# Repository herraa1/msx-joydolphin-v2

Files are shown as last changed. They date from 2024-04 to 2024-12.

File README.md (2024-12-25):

# Nintendo Gamecube controller adapter for MSX (msx-joydolphin) v2

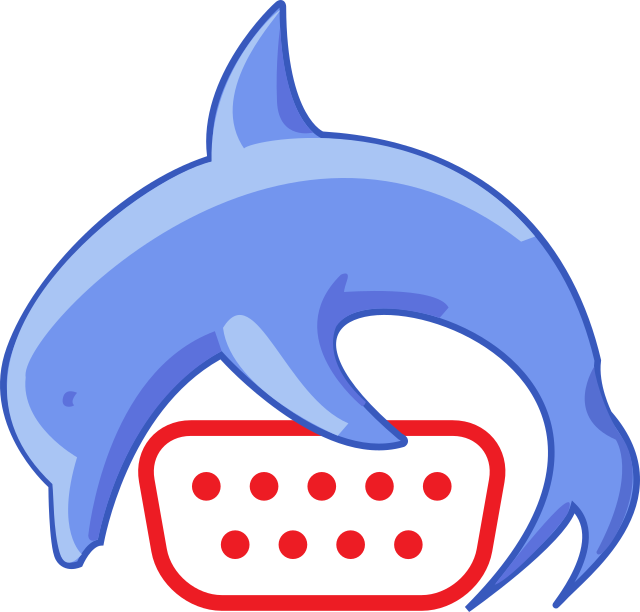
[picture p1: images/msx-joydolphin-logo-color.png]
[](images/msx-joydolphin-logo-color.png)

Connect [Nintendo Gamecube controllers](https://en.wikipedia.org/wiki/GameCube_controller) to [MSX computers](https://www.msx.org/wiki/).

> [!NOTE]
>
> No build instructions are yet provided, but if you are brave enough go for the [recommended build](#recommended-build).
>

## Introduction

The msx-joydolphin v2 is an adapter that allows connecting Nintendo Gamecube controllers to [MSX general purpose I/O ports](https://www.msx.org/wiki/General_Purpose_port).

The main features of the msx-joydolphin v2 adapter are:
* small footprint
* made of widely available electronic components
* behaves as a cord extension between the MSX computer and the Nintendo Gamecube controller
* uses a female standard DE9 connector on the adapter's MSX joystick side
* uses a Gamecube Controller socket on the adapter's Nintendo Gamecube controller side
* no need for external power supply for wired controllers, the adapter draws current from the MSX port
* low power consumption for wired controllers (<20mA)
* serial debug provides information about the operation of the adapter
* supports WaveBird Wireless Controllers (which draw up to 150mA) when powering the adapter via USB

## Changes since v1

The msx-joydolphin v2 adapter now follows the behavior of the MSX joystick reference diagram of the MSX Technical Databook,
even when pin8 of the MSX general purpose I/O port is HIGH.
This makes the adapter now work seamlessly with MSX-HID, which required entering FM Towns compatibility mode
in msx-joydolphin v1.

## Adapter Name

Why msx-joydolphin?
The first part of the name is pretty obvious: _"msx"_ as this is an adapter for MSX computers and _"joy"_ as this is a joystick adapter.
The _"dolphin"_ part comes from the project codename assigned to the Nintendo Gamecube during its development.

## [Hardware](hardware/kicad/)

The msx-joydolphin v2 adapter uses an [Arduino Nano](https://store.arduino.cc/products/arduino-nano) to convert the [Nintendo Gamecube controller signalling](http://www.int03.co.uk/crema/hardware/gamecube/gc-control.html) to the [MSX joystick standard signalling](https://www.msx.org/wiki/Joystick_control).

A small printed circuit board (PCB) is used to easily bind all components:
* The Arduino Nano is connected using female headers (or soldered directly, when using the proposed the plastic case)
* PH2.0 connectors are used to connect cable extensions
* A 2.54 pitch debug header is added for convenience
* Through-hole components are used on the front side
* Surface mount device (SMD) components are used on the back side
  * The SMD components use footprints and sizes (1206) to make hand-soldering easier

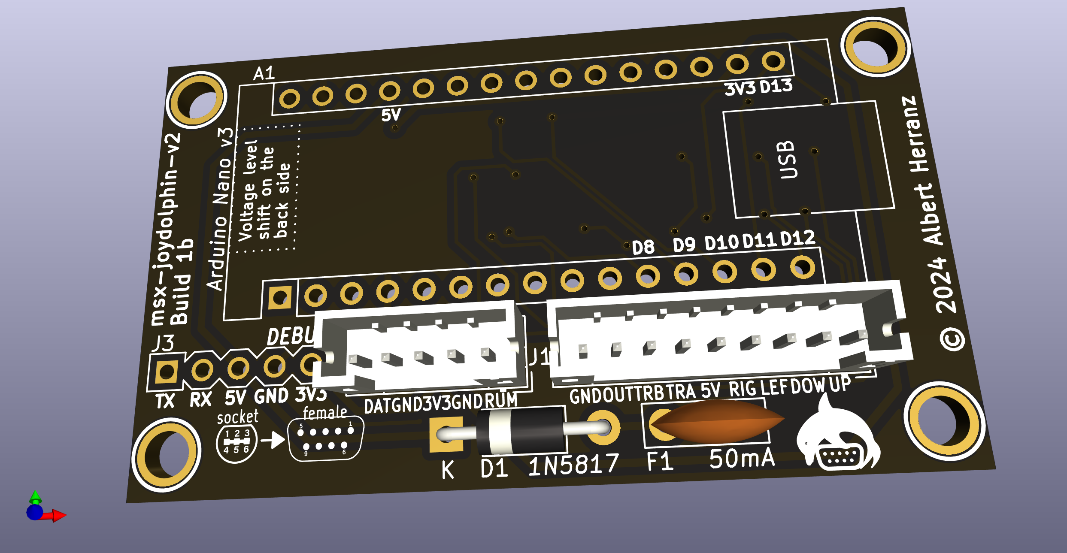
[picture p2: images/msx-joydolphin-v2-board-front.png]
[](images/msx-joydolphin-v2-board-front.png)
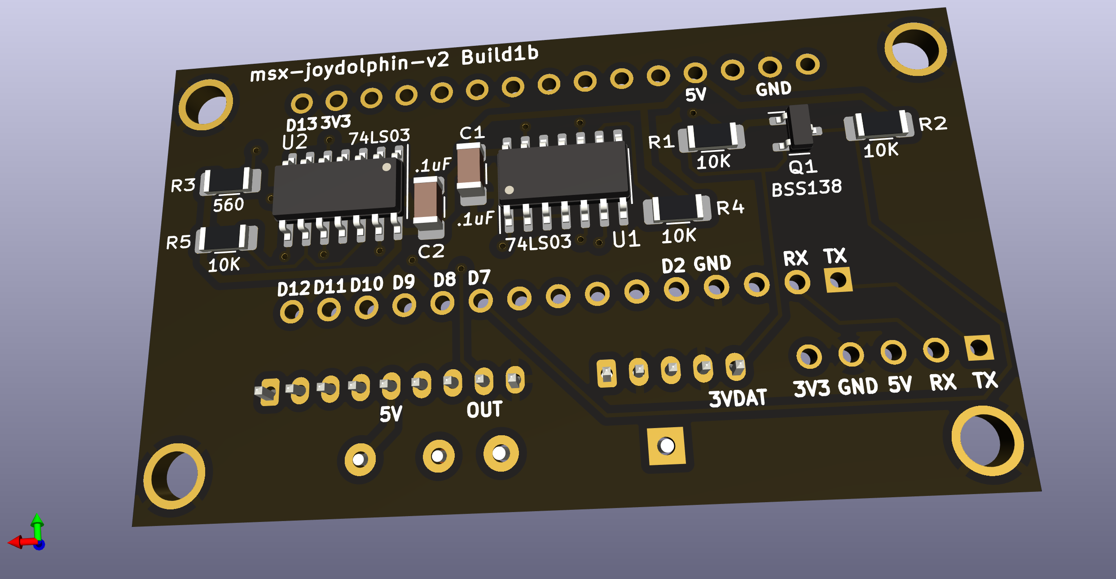
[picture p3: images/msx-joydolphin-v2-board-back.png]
[](images/msx-joydolphin-v2-board-back.png)

Connection to the MSX general purpose I/O port is implemented using a DE9 joystick extension cable with a female DE9 connector on one side and a loose end on the other side.
The MSX joystick extension cable loose end is wired according to the following pinout mapping.

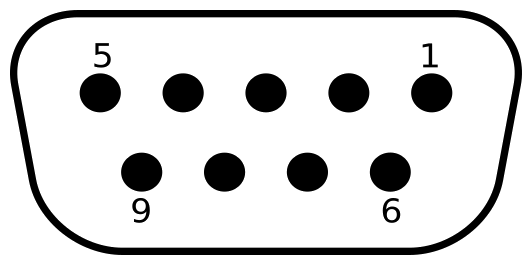
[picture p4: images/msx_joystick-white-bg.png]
| [](images/msx_joystick-white-bg.png) |
|:--|
| MSX joystick connector pinout, from controller plug side |

| MSX side pin | Cable color (may vary) | Signal | Arduino Nano side (port/pin/number) |
| --- | --- | --- | --- |
| 5 | Brown | +5v | _/5V/27 |
| 4 | Orange | RIGHT  | PB3/D11/14 |
| 3 | Grey | LEFT | PB2/D10/13 |
| 2 | Black | DOWN | PB1/D9/12 |
| 1 | Red | UP | PB0/D8/11 |
| 6 | Green | TRIGA  | PB4/D12/15 |
| 7 | White | TRIGB  | PB5/D13/16 |
| 8 | Blue | OUT | PD2/D2/5 |
| 9 | Yellow | GND | _/GND/4,29 |

The msx-joydolphin-v2 is fully compatible with MSX joysticks and honors the pin8 (OUT) signal.

The adapter uses open collector outputs (using 74LS03 Quad 2-Input NAND gates with open collector outputs) which makes the adapter safer [^3] than the
standard MSX joystick schematic depicted in the MSX Technical Data Book, as it avoids a series of undesired conditions that can lead to bus contention/short circuits.

Power is drawn from the +5V signal of the MSX general purpose I/O port, which is capable of delivering up to 50mA [^1].
The msx-joydolphin v2 draws below 20mA from the port when a wired controller is connected, so it is on the safe side. Anyway, the msx-joydolphin adapter uses a Positive Temperature Coeficient (PTC) resettable fuse of 50mA (F1) to limit current in case something goes wrong.

Also on the power side, a [1N5817 Schottky diode](https://www.onsemi.com/download/data-sheet/pdf/1n5817-d.pdf) (D1) is used to avoid leaking current from the msx-joydolphin adapter to the MSX in case the USB port of the Arduino Nano is connected to a computer or power supply while the adapter is plugged into an MSX.

Connection to the Nintendo Gamecube controller is done via a Nintendo Gamecube controller extension cable with a controller socket on one side and a loose end on the other side.
The Nintendo Gamecube controller extension cable loose end is wired according to the following pinout mapping.

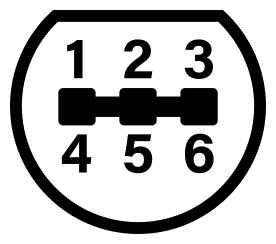
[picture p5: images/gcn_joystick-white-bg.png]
| [](images/gcn_joystick-white-bg.png) |
|:--|
| Nintendo Gamecube connector pinout, from Nintendo Gamecube side |

| Gamecube socket pin | Cable color official | Cable color actual (may vary) | Signal | Comment | Arduino Nano side (port/pin/number) |
| --- | ---| --- | --- | --- | --- |
| 1 | Yellow | White | +5v | rumble, not used | N/C |
| 2 | Red | Red | DAT | data line, uses 3v3 logic so it connects via a level shifter to PD7/D7/10 | \*( PD7/D7/10 ) |
| 3 | Green | Black | GND | ground | _/GND/4,29 |
| 4 | White | Blue | GND | ground | _/GND/4,29 |
| 5 | | | | | N/C |
| 6 | Blue | Green | 3.43v  | power line, 3v3 | _/3v3/17 |
| 7 | Black | N/A | GND | ground | N/C |

The Nintendo Gamecube controller uses 3.3V for power and logic, except for the rumble motor which uses 5V.

Power for the Nintendo Gamecube controller is provided by the 3.3V pin of the FT232RL integrated in the Arduino Nano, which is capable of delivering up to 50mA [^2], enough to power a wired game controller.

As the Arduino Nano is a 5V logic microcontroller, the msx-joydolphin adapter uses a voltage level shifter based on the [BSS138 N-Channel Logic Level Enhancement Mode Field Effect Transistor](https://www.onsemi.com/pdf/datasheet/bss138-d.pdf) (Q1) to convert the Nintendo Gamecube controller DAT signal between 3.3V and 5V logic levels.

> [!WARNING]
> Do NOT connect the DAT line of the Nintendo Gamecube controller to the Arduino Nano directly, always use a voltage level shifter.
> The game controller may get damaged if you connect a 5V signal directly to the 3.3V DAT line.

If a WaveBird Wireless Controller is connected then the msx-joydolphin adapter needs to be powered via the mini USB port of the Arduino Nano, as the power consumption (150mA) is higher than what the MSX joystick port can deliver.
Althought it won't work, it is safe to connect a WaveBird Wireless Controller dongle without connecting an external USB power supply thanks to the current limitation of the PTC.
Also, connection of an external USB power supply to the Arduino Nano won't back-power the MSX computer thanks to the Schottky diode reverse current protection.

### Recommended Build

Please, use [msx-joydolphin-v2 Build1b](#build1b) for making new boards if you want something field-tested.

### [Build1b](hardware/kicad/msx-joydolphin-v2-Build1b)

[Bill Of Materials (BoM)](https://html-preview.github.io/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)

The Build1b adapter mimics completely the standard MSX joystick behaviour:

* When pin8 is HIGH, the adapter puts all stick and triggers signals in high impedance mode irrespective of their status (as if stick and triggers were not hold in the standard MSX joystick schematic), which become HIGH on the MSX side via the MSX PSG related circuitry pull-ups (matching the expected behavior)
* When pin8 is LOW
  * if a stick direction or trigger is hold, the corresponding signal is pulled down to GND causing it to be LOW (matching the expected behavior)
  * if a stick direction or trigger is not hold, the corresponding signal is put in high impedance mode, which becomes HIGH on the MSX side via the MSX PSG related circuitry pull-ups (matching the expected behaviour)

This build uses discrete logic components to honor the pin8 signaling (two [74LS03DR quad 2-input positive-nand gates with open collector outputs](https://www.ti.com/lit/ds/symlink/sn74ls03.pdf)) and uses open collector outputs which makes the adapter safer [^3] than the standard MSX joystick schematic depicted in the MSX Technical Data Book, as it avoids a series of undesired conditions that can lead to bus contention/short circuits.

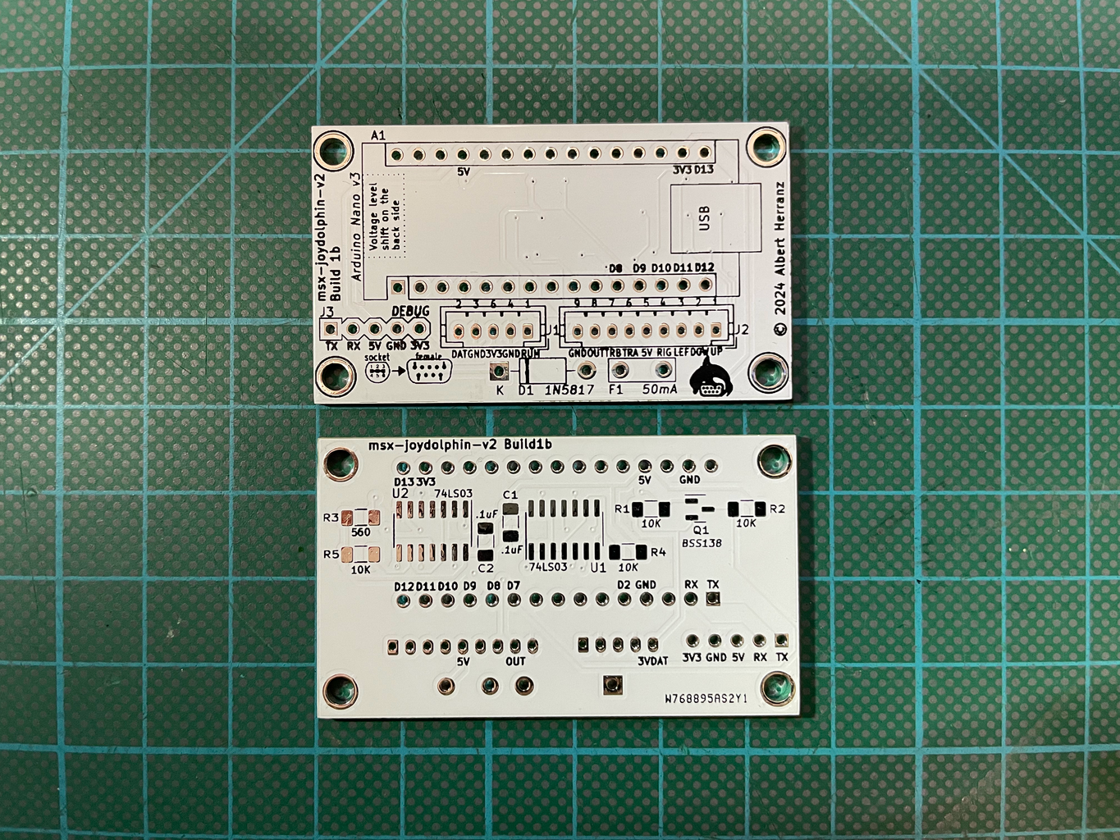
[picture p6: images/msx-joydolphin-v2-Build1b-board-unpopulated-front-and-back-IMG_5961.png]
|[](images/msx-joydolphin-v2-Build1b-board-unpopulated-front-and-back-IMG_5961.png)|
|:--|
|msx-joydolphin-v2 Build1b first prototype unpopulated|

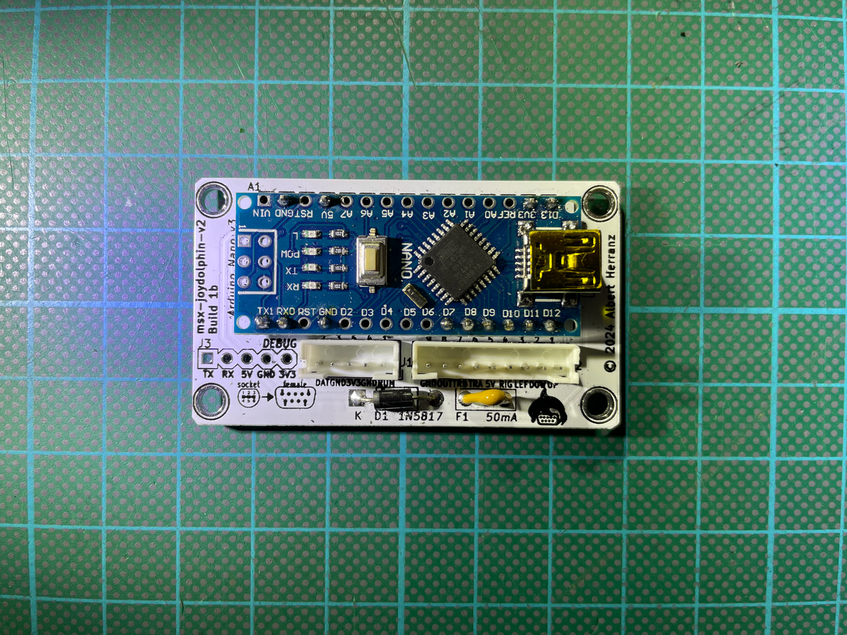
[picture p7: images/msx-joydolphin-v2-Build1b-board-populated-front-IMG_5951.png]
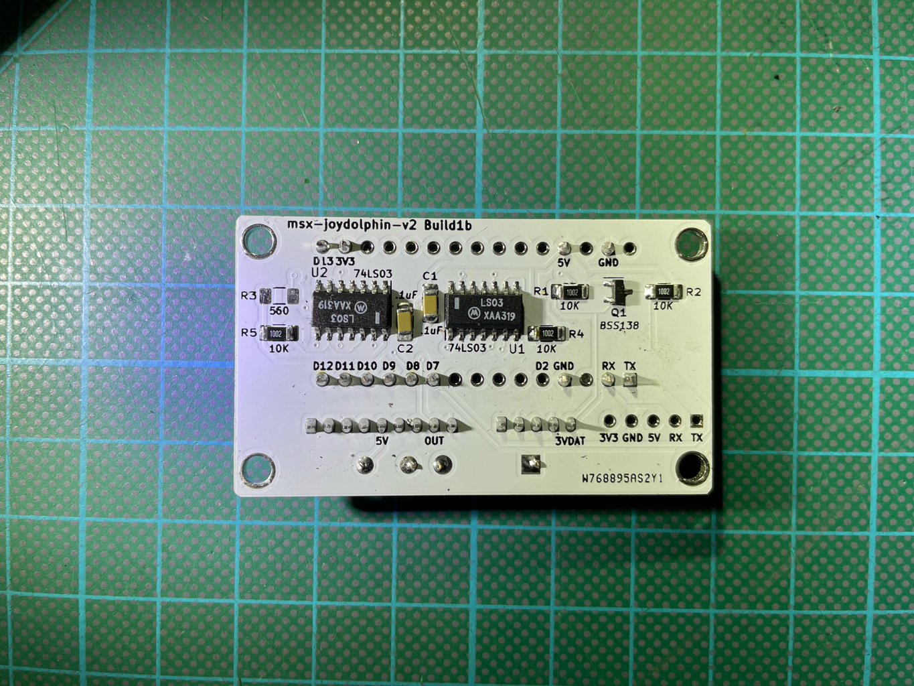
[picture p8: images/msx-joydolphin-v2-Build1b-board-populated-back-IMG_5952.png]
|[](images/msx-joydolphin-v2-Build1b-board-populated-front-IMG_5951.png)|[](images/msx-joydolphin-v2-Build1b-board-populated-back-IMG_5952.png)|
|-|-|
|msx-joydolphin-v2 Build1b front populated|msx-joydolphin-v2 Build1b rear populated|

> [!NOTE]
> Do NOT populate resistor R3 as it is not needed.

## [Firmware](firmware/msx-joydolphin-v2/)

The msx-joydolphin v2 adapter firmware uses [NicoHood's Nintendo library](https://github.com/NicoHood/Nintendo) to read the Nintendo Gamecube controller status, and it is heavily inspired on [Daniel Jose Viana "Danjovic" firmware](https://github.com/Danjovic/MSX/blob/master/NSX-64) for a similar adapter for Nintendo 64 joysticks.

The following elements are used as inputs:
* digital pad (D-Pad), as direction arrows
* analog pad, as direction arrows
* A button, as Trigger 1
* B button, as Trigger 2

Those elements' status are processed by the msx-joydolphin firmware and transformed into MSX general purpose I/O port's signals on the fly.

## [Enclosure](enclosure/)

### Acrylic

A simple acrylic enclosure design for the project is provided to protect the electronic components and provide strain relief for the extension cords.

The enclosure uses a 3mm acrylic sheet.

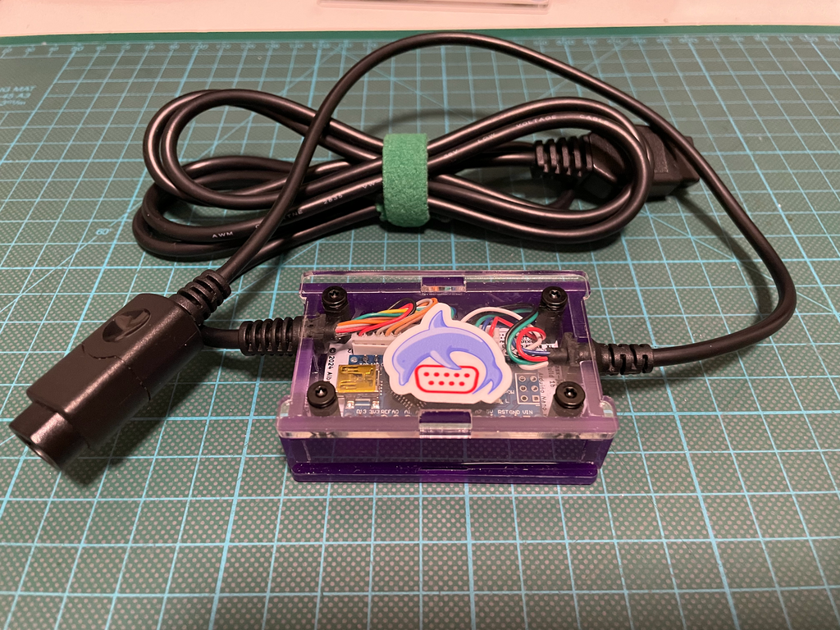
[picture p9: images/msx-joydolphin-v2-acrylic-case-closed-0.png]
[](images/msx-joydolphin-v2-acrylic-case-closed-0.png)
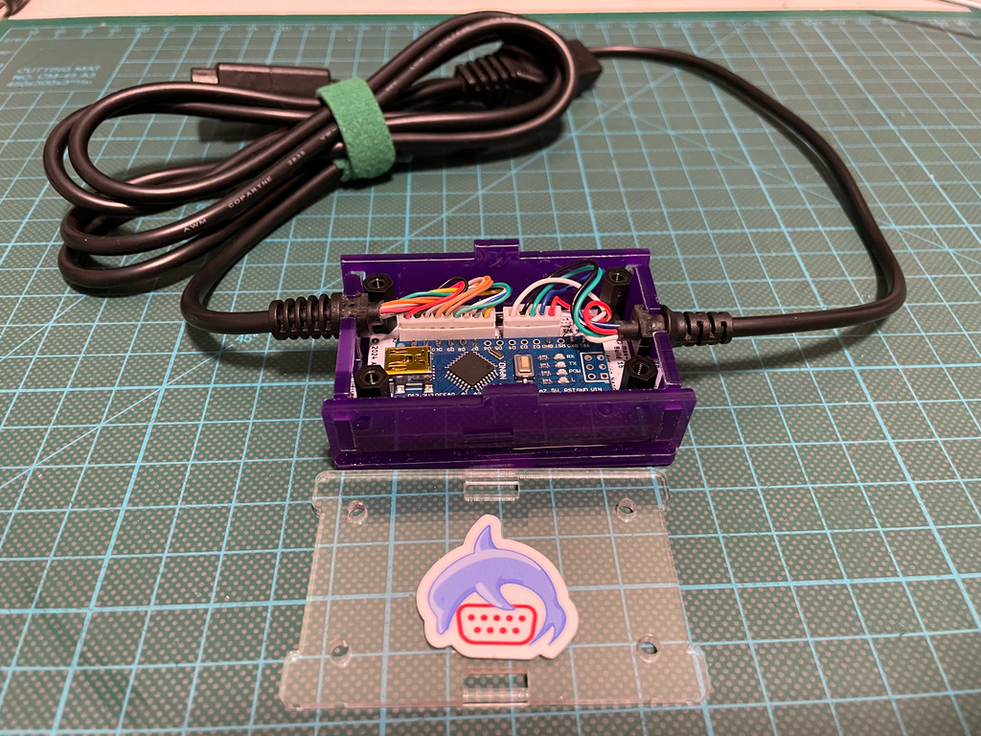
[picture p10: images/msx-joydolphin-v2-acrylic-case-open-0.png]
[](images/msx-joydolphin-v2-acrylic-case-open-0.png)
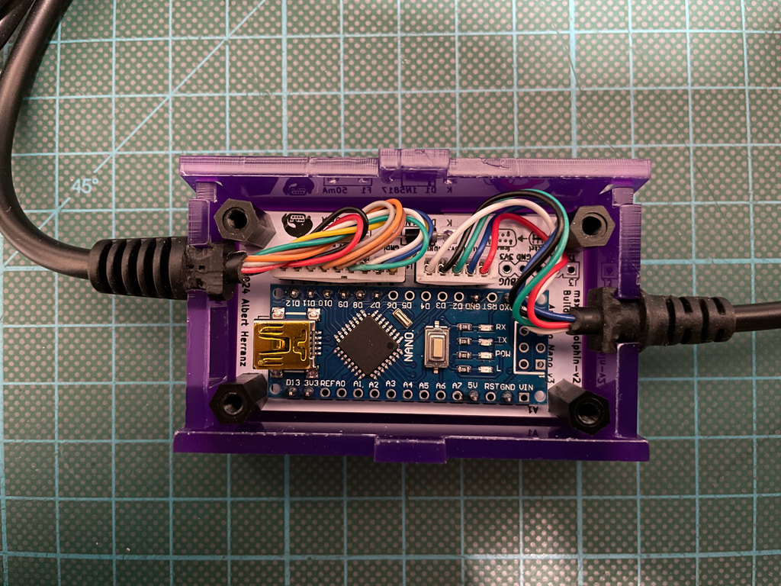
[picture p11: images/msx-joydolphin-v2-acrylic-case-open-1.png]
[](images/msx-joydolphin-v2-acrylic-case-open-1.png)

The enclosure allows access to the USB port of the Arduino Nano without having to open it.

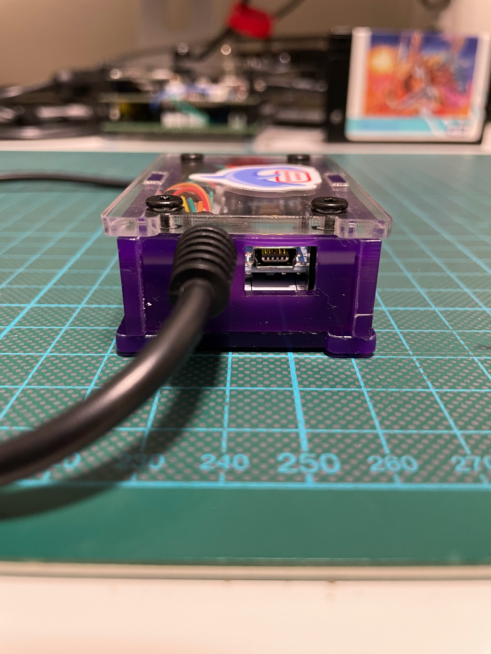
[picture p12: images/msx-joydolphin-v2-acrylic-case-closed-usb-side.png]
[](images/msx-joydolphin-v2-acrylic-case-closed-usb-side.png)

> [!NOTE]
> The height of the acrylic enclosure for msx-joydolphin-v2 has been reduced, so the Arduino Nano must be soldered in the same way as when using the plastic enclosure.

### Plastic

Another enclosure option is using an off-the-shelf [plastic case of 60x36x17mm](https://es.aliexpress.com/item/1005002139025547.html).

When using this option, the Arduino Nano must be soldered directly to the msx-joydolphin v2 board and its pin header legs must be trimmed down in order to fit within the reduced space of the case.

Also, you may need to trim a bit the pcb board corners with a file to slide the board into the case.

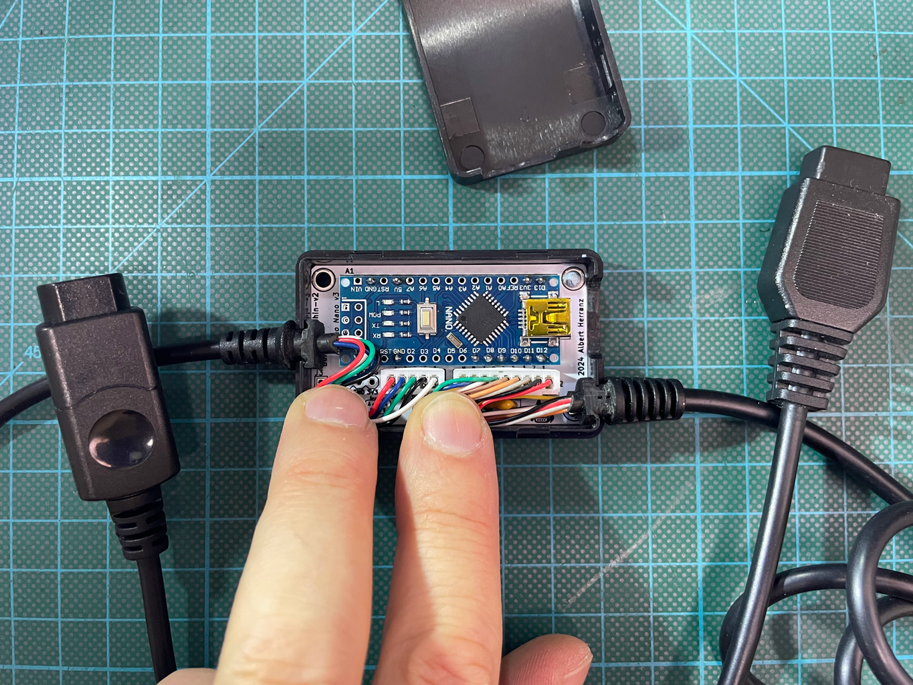
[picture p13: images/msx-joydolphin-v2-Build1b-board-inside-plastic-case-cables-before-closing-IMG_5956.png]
[](images/msx-joydolphin-v2-Build1b-board-inside-plastic-case-cables-before-closing-IMG_5956.png)
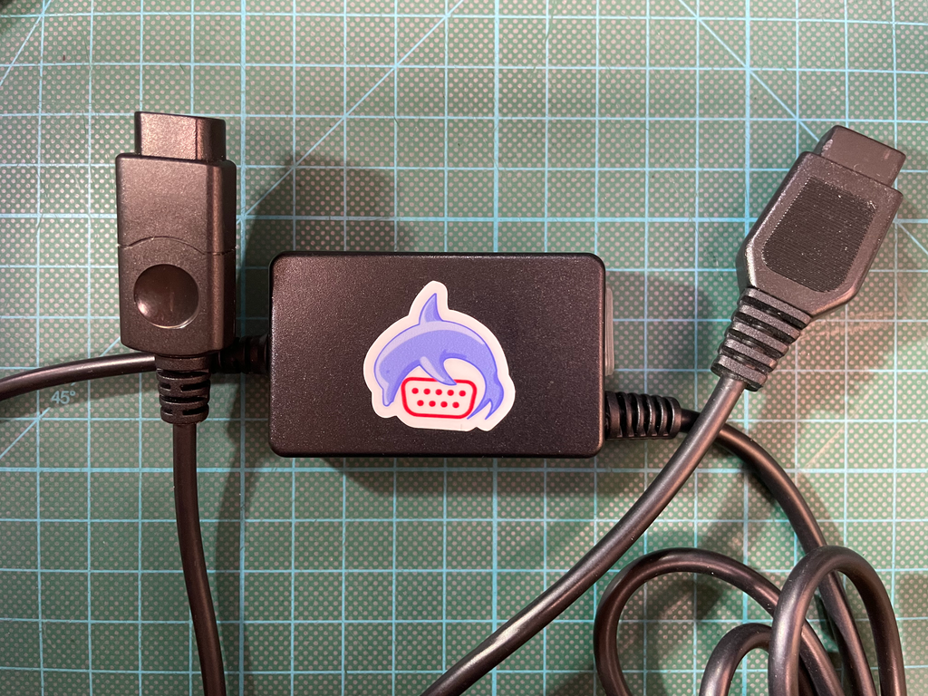
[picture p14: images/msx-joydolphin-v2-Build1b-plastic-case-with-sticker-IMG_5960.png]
[](images/msx-joydolphin-v2-Build1b-plastic-case-with-sticker-IMG_5960.png)

You can enlarge the existing hole on one of the case sides to access the mini USB connector, and make a new hole on the very left of the same side for the MSX joystick cable.

This way you can easily power the adapter via USB when you connect a Wavebird wireless controller.

You can use a plastic cover (a HDMI cover in this case) to protect the mini USB hole when not in use, as seen on the pictures.

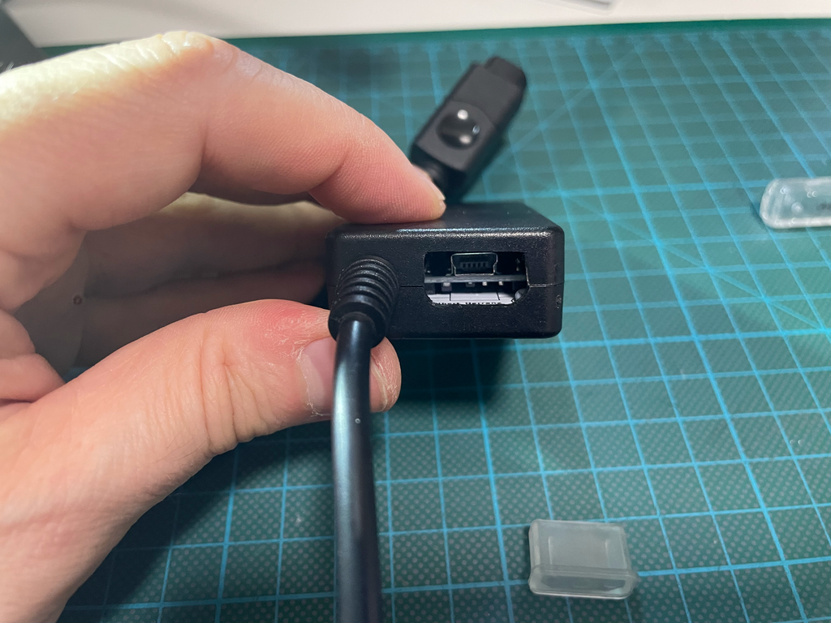
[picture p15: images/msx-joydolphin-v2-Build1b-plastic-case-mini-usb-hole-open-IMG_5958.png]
[](images/msx-joydolphin-v2-Build1b-plastic-case-mini-usb-hole-open-IMG_5958.png)
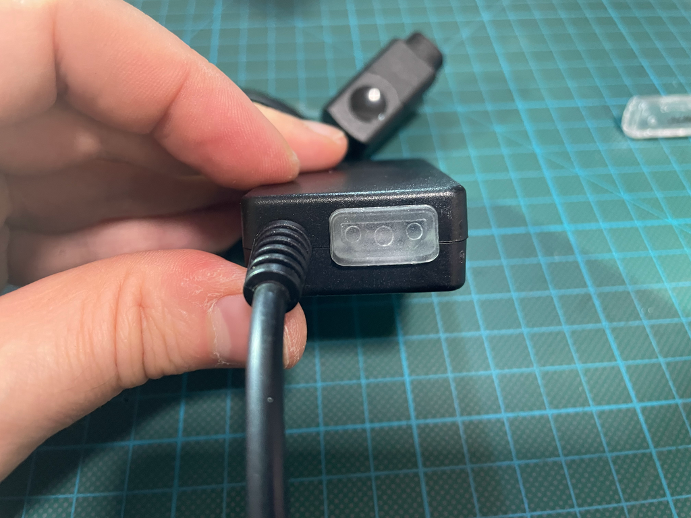
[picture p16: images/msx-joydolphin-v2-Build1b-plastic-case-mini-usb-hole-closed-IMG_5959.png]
[](images/msx-joydolphin-v2-Build1b-plastic-case-mini-usb-hole-closed-IMG_5959.png)

## References

MSX general purpose I/O port
* https://www.msx.org/wiki/General_Purpose_port

Gamecube controller pinout
* https://allpinouts.org/pinouts/connectors/videogame/nintendo-gamecube-controller-connector-pinout/
* http://www.int03.co.uk/crema/hardware/gamecube/gc-control.html

Arduino Nano pinout
* https://content.arduino.cc/assets/Pinout-NANO_latest.pdf
* https://www.makerguides.com/arduino-nano/

Nico Hood Nintendo Gamecube Joystick arduino library
* https://github.com/NicoHood/Nintendo

Daniel Jose Viana "Danjovic" NSX-64 project
* https://github.com/Danjovic/MSX/blob/master/NSX-64

Gamecube controller IDs
* https://www.gc-forever.com/yagcd/chap9.html#sec9

[^1]: https://www.msx.org/wiki/General_Purpose_port
[^2]: https://www.mouser.es/datasheet/2/163/DS_FT232R-11534.pdf
[^3]: https://www.msx.org/wiki/Joystick/joypad_controller (see "Undesired Conditions")

## Image Sources

* https://www.oshwa.org/open-source-hardware-logo/
* https://consolemods.org/wiki/images/a/a1/GameCube_Controller_Pinout.svg
* https://en.wikipedia.org/wiki/File:Numbered_DE9_Diagram.svg
* https://commons.wikimedia.org/wiki/File:Video_Game_Controller_(56427)_-_The_Noun_Project.svg
* https://logo-timeline.fandom.com/wiki/GameCube?file=Nintendo_Dolphin_1999.svg

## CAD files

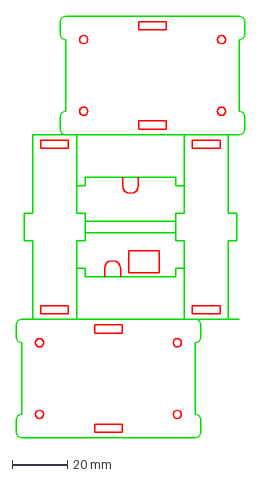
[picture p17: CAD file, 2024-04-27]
enclosure/msx-joydolphin-v2-case-acrylic-3mm-ready-to-lasercut.dxf
83.0 x 153.0 mm

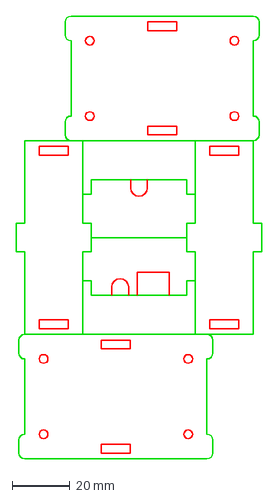
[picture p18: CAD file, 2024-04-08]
enclosure/msx-joydolphin-v2-case.dxf
85.0 x 153.0 mm

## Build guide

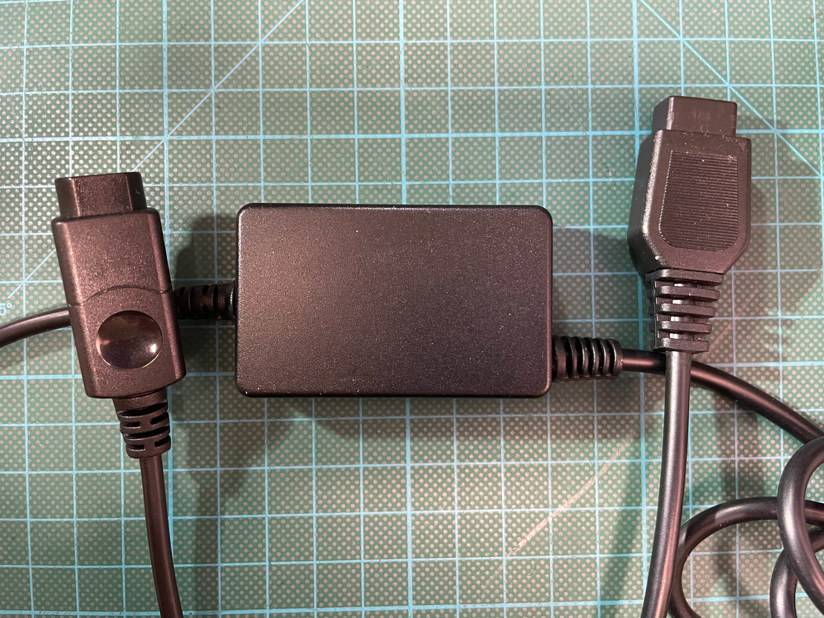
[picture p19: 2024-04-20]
images/msx-joydolphin-v2-Build1b-plastic-case-closed-IMG_5957.png

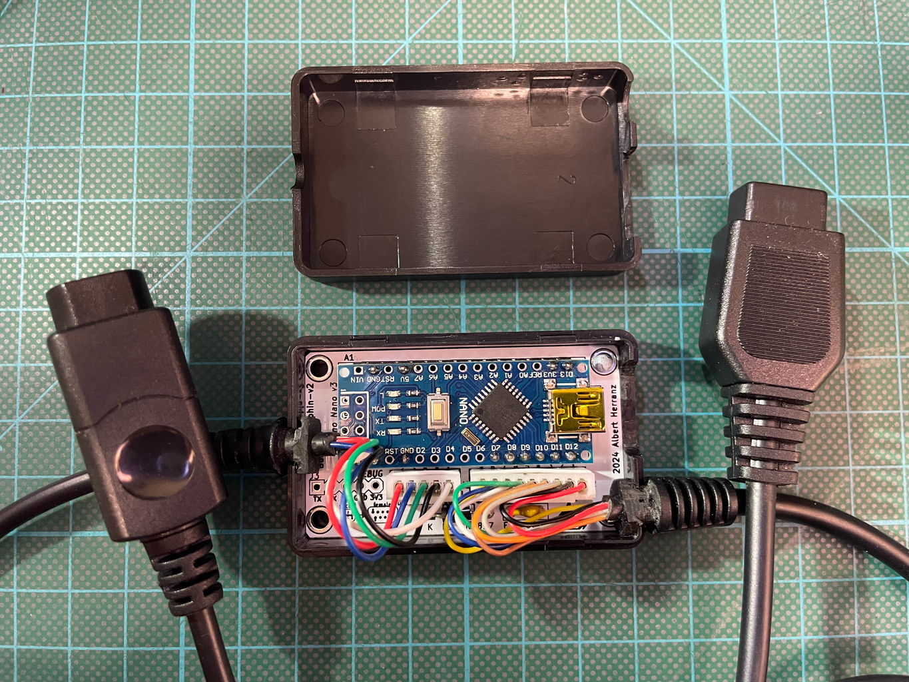
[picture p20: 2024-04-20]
images/msx-joydolphin-v2-Build1b-board-inside-plastic-case-with-gamamecube-and-msx-cable-IMG_5955.png

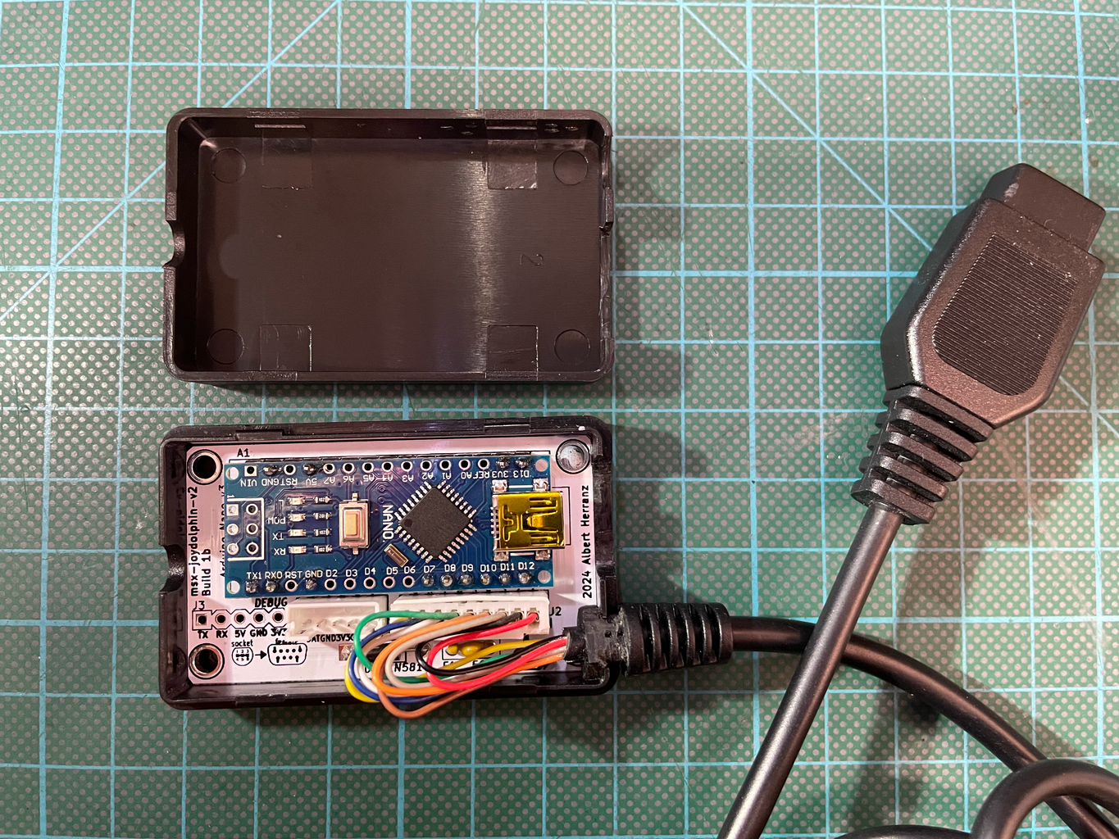
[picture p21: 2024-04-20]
images/msx-joydolphin-v2-Build1b-board-inside-plastic-case-with-msx-cable-IMG_5954.png

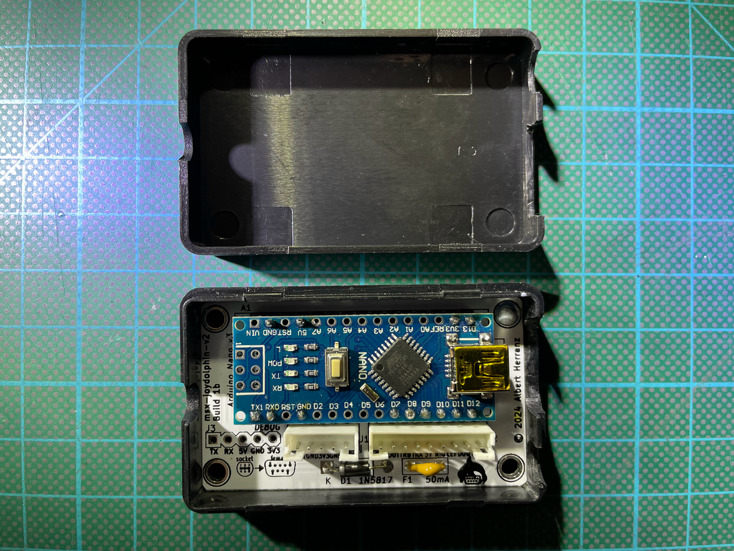
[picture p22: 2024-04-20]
images/msx-joydolphin-v2-Build1b-board-inside-plastic-case-IMG_5953.png

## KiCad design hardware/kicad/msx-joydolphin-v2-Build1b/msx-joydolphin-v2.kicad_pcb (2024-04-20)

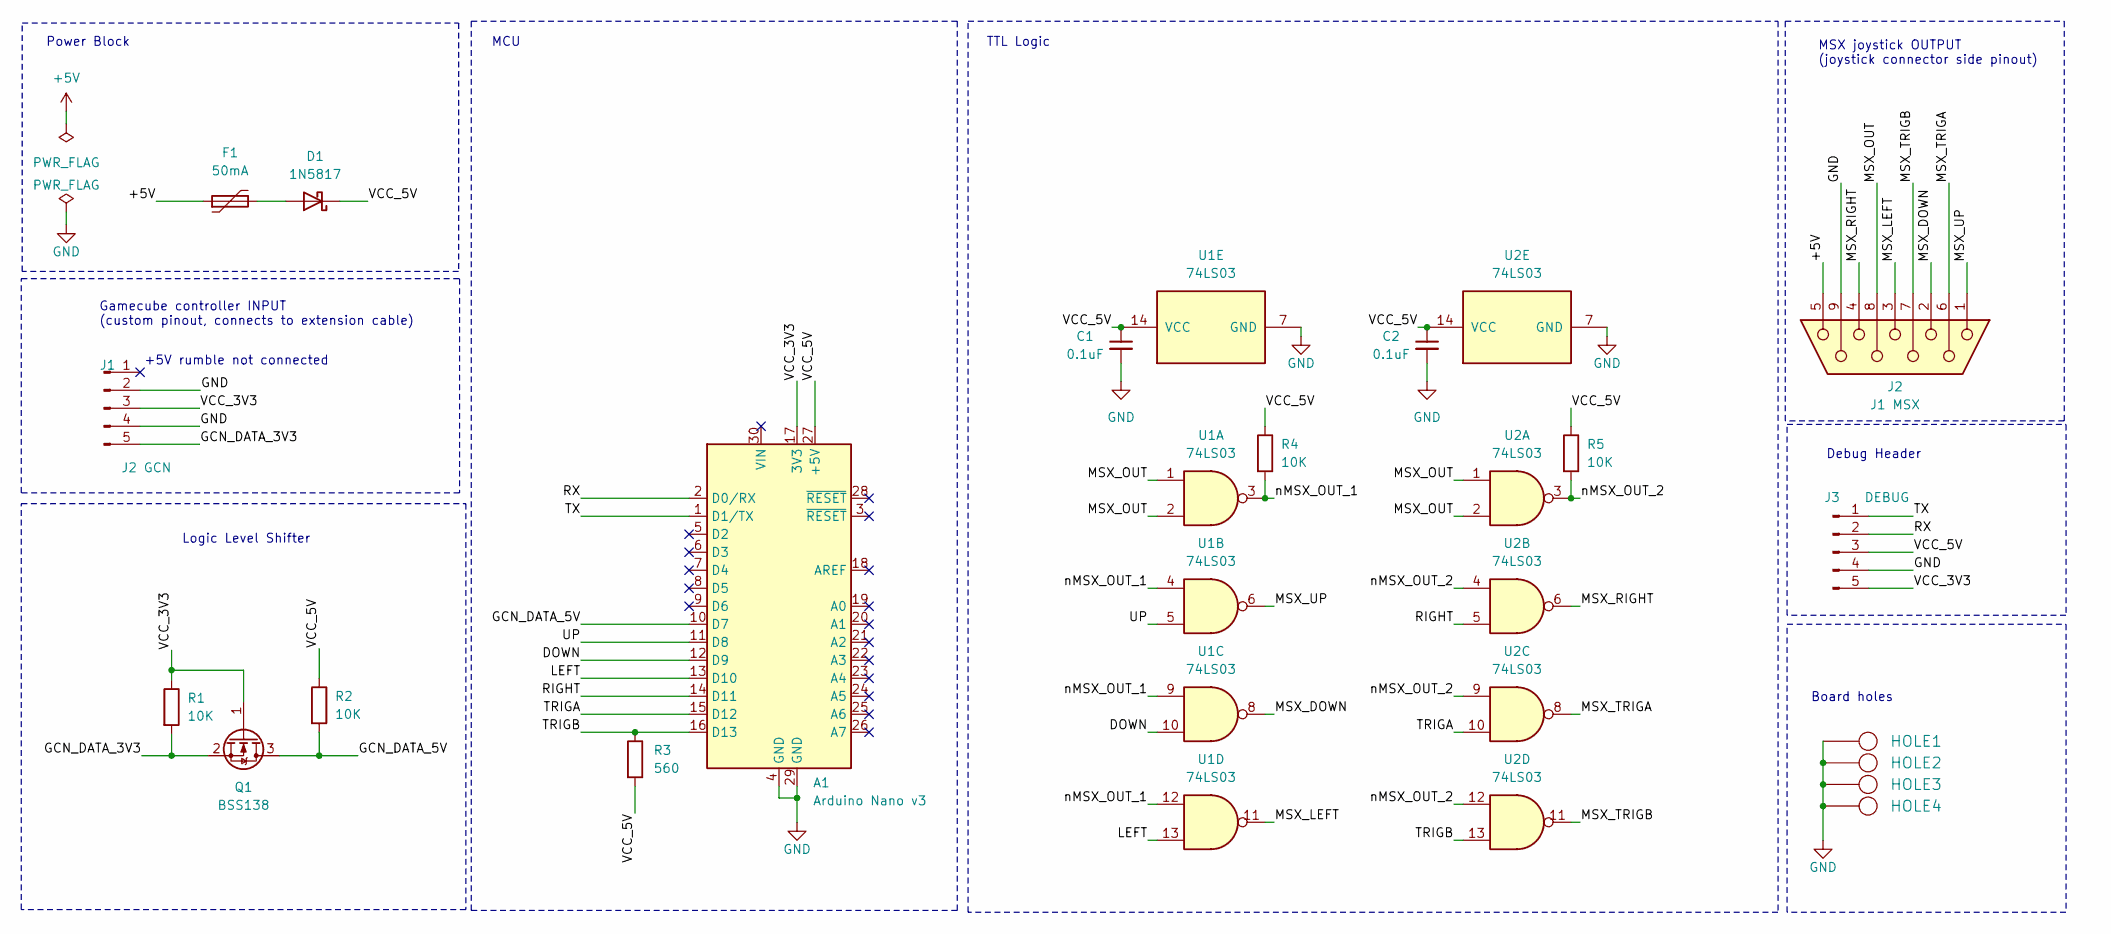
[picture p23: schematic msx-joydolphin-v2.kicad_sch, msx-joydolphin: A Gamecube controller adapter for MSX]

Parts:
A1: Arduino Nano v3; Arduino_Nano
C1, C2: 0.1uF; C_1206_3216Metric_Pad1.33x1.80mm_HandSolder
D1: 1N5817; D_DO-41_SOD81_P10.16mm_Horizontal
F1: 50mA; C_Disc_D7.5mm_W2.5mm_P5.00mm
HOLE1, HOLE2, HOLE3, HOLE4: HOLE; Hole_3mm
J1: J2 GCN; JST_PH_B5B-PH-K_1x05_P2.00mm_Vertical
J2: J1 MSX; JST_PH_B9B-PH-K_1x09_P2.00mm_Vertical
J3: DEBUG; Conn_Pin_Header_5x1_2.54mm
Q1: BSS138; SOT-23
R1, R2, R4, R5: 10K; R_1206_3216Metric_Pad1.30x1.75mm_HandSolder
R3: 560; R_1206_3216Metric_Pad1.30x1.75mm_HandSolder
U1, U2: 74LS03; SOIC-14_3.9x8.7mm_P1.27mm

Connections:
+5V: F1.1, J2.5
/DOWN: A1.12 (D9), U1.10
/GCN_DATA_3V3: J1.5, Q1.2 (S), R1.2
/GCN_DATA_5V: A1.10 (D7), Q1.3 (D), R2.2
/LEFT: A1.13 (D10), U1.13
/MSX_DOWN: J2.2, U1.8
/MSX_LEFT: J2.3, U1.11
/MSX_OUT: J2.8, U1.1, U1.2, U2.1, U2.2
/MSX_RIGHT: J2.4, U2.6
/MSX_TRIGA: J2.6, U2.8
/MSX_TRIGB: J2.7, U2.11
/MSX_UP: J2.1, U1.6
/RIGHT: A1.14 (D11), U2.5
/RX: A1.2 (D0/RX), J3.2
/TRIGA: A1.15 (D12), U2.10
/TRIGB: A1.16 (D13), R3.1, U2.13
/TX: A1.1 (D1/TX), J3.1
/UP: A1.11 (D8), U1.5
/VCC_3V3: A1.17 (3V3), J1.3, J3.5, Q1.1 (G), R1.1
/VCC_5V: A1.27 (+5V), C1.1, C2.1, D1.1 (K), J3.3, R2.1, R3.2, R4.1, R5.1, U1.14 (VCC), U2.14 (VCC)
/nMSX_OUT_1: R4.2, U1.3, U1.4, U1.9, U1.12
/nMSX_OUT_2: R5.2, U2.3, U2.4, U2.9, U2.12
GND: A1.4 (GND), A1.29 (GND), C1.2, C2.2, HOLE1.1, HOLE2.1, HOLE3.1, HOLE4.1, J1.2, J1.4, J2.9, J3.4, U1.7 (GND), U2.7 (GND)
unnamed: D1.2 (A), F1.2

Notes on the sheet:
Power Block
Debug Header
TTL Logic
+5V rumble not connected
MCU
Board holes
Logic Level Shifter
MSX joystick OUTPUT (joystick connector side pinout)
Gamecube controller INPUT (custom pinout, connects to extension cable)

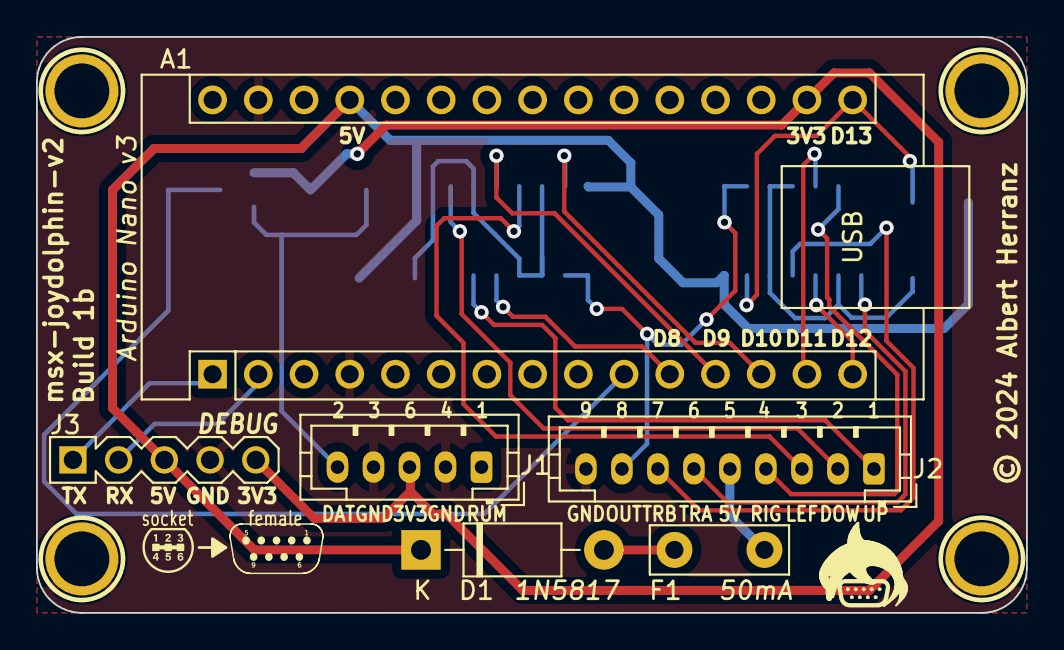
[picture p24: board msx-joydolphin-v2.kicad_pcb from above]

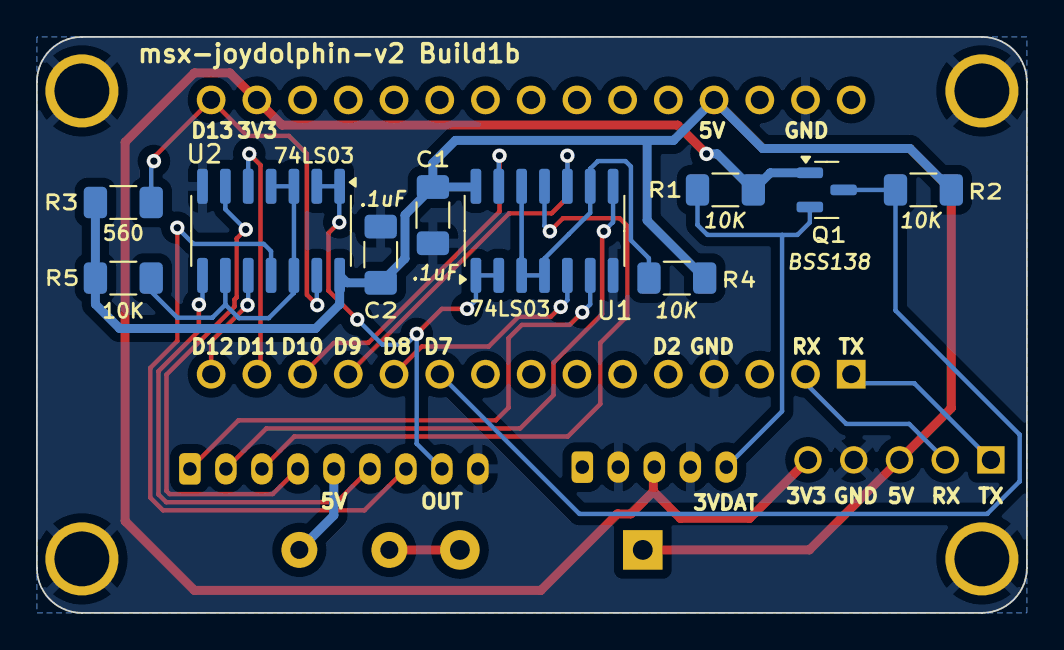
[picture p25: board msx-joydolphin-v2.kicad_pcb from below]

Board: 2 copper layers, 55.0 x 32.0 mm, 20 parts (10 on the bottom side), 24 nets.

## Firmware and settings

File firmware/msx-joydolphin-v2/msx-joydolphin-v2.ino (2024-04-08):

/*
 * msx-joydolphin v2, a Gamecube controller to MSX joystick adapter
 * Copyright (C) 2023-2024 Albert Herranz
 *
 * This code is released under GPL V2.0
 *
 * Valid-License-Identifier: GPL-2.0-only
 * SPDX-URL: https://spdx.org/licenses/GPL-2.0-only.html
 *
 * Based on previous work by:
 * - Daniel Jose Viana "Danjovic" NSX-64 project, https://github.com/Danjovic/MSX/tree/master/NSX-64/firmware/nsx-64
 * - NicoHood Nintendo library, https://github.com/NicoHood
 *
 * Other references:
 * - http://www.int03.co.uk/crema/hardware/gamecube/gc-control.html
 * - https://www.msx.org/wiki/General_Purpose_port
 */

#include <avr/sleep.h>
#include <avr/power.h>
#include <avr/interrupt.h>
#include "Nintendo.h"

/*
 * Debugging helpers
 */
/* #define DEBUG */

#ifdef DEBUG
  #define DEBUG_PRINTLN(x)  Serial.println (x)
#else
  #define DEBUG_PRINTLN(x)
#endif

/* Nintendo Gamecube controller pad axis valid range */
#define GCN_AXIS_MIN 0
#define GCN_AXIS_MAX 255

/*
 * Arduino Nano pins for MSX signals.
 * Use PORTB for all MSX joystick arrow and buttons signals.
 * This allows to set them all at the same time.
 */
#define PORT_MSX_JOYSTICK PORTB
#define DDR_MSX_JOYSTICK  DDRB

/* MSX general purpose signals as mapped to Arduino Nano PORTB bits */
const int PORT_MSX_JOYSTICK_UP       = 0; /* PB0, MSX joystick pin1 */
const int PORT_MSX_JOYSTICK_DOWN     = 1; /* PB1, MSX joystick pin2 */
const int PORT_MSX_JOYSTICK_LEFT     = 2; /* PB2, MSX joystick pin3 */
const int PORT_MSX_JOYSTICK_RIGHT    = 3; /* PB3, MSX joystick pin4 */
const int PORT_MSX_JOYSTICK_TRIGGER1 = 4; /* PB4, MSX joystick pin6 */
const int PORT_MSX_JOYSTICK_TRIGGER2 = 5; /* PB5, MSX joystick pin7 */ /* LED_BUILTIN */

/* Nintendo Gamecube joystick controller */
CGamecubeController GamecubeController1(7); /* PD7 for DAT I/O */

uint8_t curr_msx_joystick_signals = 0x00;

/*
 * Discrete thresholds for Nintendo Gamecube joystick analog pad axis:
 * - Values below the min threshold on the horizontal/vertical axis indicate
 *   left/down active, respectively.
 * - Values above the max threshold on the horizontal/vertical axis indicate
 *   right/up active, respectively.
 */
int axis_threshold_min, axis_threshold_max;

/* serial output width control */
uint8_t output_width_count = 0;

void print_hex8(uint8_t data)
{
    char tmp[2+1];
    byte nibble;

    nibble = (data >> 4) | 48;
    tmp[0] = (nibble > 57) ? nibble + (byte)39 : nibble;
    nibble = (data & 0x0f) | 48;
    tmp[1] = (nibble > 57) ? nibble + (byte)39 : nibble;
    tmp[2] = 0;

    Serial.print(tmp);
}

void print_hex16(uint16_t data)
{
    print_hex8((uint8_t)(data >> 8));
    print_hex8((uint8_t)(data & 0xff));
}

void print_rolling_sequence(void)
{
    static char rolling_chars[] = { '-', '\\', '|', '/' };
    static uint8_t rolling_index = 0;

    Serial.print(rolling_chars[rolling_index++]);
    if (rolling_index >= sizeof(rolling_chars))
        rolling_index = 0;
}

void setup()
{
    int axis_threshold;

    /* initialize all joystick signals to inactive */
    __update_msx_signals(0x00);

    /* use the serial port for debugging purposes */
    Serial.begin(9600);
    Serial.println("msx-joydolphin-v2 20240222_1");

    /*
     * Calculate Nintendo Gamecube controller analog pad thresholds.
     * Analog pad needs to be pushed from its origin in one direction at least
     * 1/6 of the complete run to get active
     */
    axis_threshold = (GCN_AXIS_MAX - GCN_AXIS_MIN) /3;
    axis_threshold_min = GCN_AXIS_MIN + axis_threshold;
    axis_threshold_max = GCN_AXIS_MAX - axis_threshold;

    GamecubeController1.begin(); /* initialize controller */
}

void loop()
{
    loop_gamecube_controller();
}

inline void __update_msx_signals(uint8_t signals)
{
    /*
     * signals variable bit definitions
     * bit5  bit4  bit3  bit2  bit1  bit0
     * TRG2  TRG1  RIGHT LEFT  DOWN  UP
     *
     * - bit unset : joystick arrow/button is not pressed
     *               configure associated GPIO as HIGH/OUTPUT (logic "1")
     * - bit set   : joystick arrow/button is pressed
     *               configure associated GPIO as LOW/OUTPUT (logic "0")
     *
     * Note that v2 uses different signal meanings than v1, and uses specific
     * hardware to honor the pin8 signal and to provide open collector outputs.
     */

    /* write all signal states at once to MSX side */
    PORT_MSX_JOYSTICK = (signals);
    DDR_MSX_JOYSTICK = (~0);
}

void loop_gamecube_controller()
{
    static bool was_connected = false;
    bool is_connected;
    uint16_t device;
    Gamecube_Report_t report;

    is_connected = GamecubeController1.connected();
    if (!is_connected) {
        /*
         * Make sure that no arrow/buttons stay pressed when
         * a gamecube controller is not connected.
         */
        curr_msx_joystick_signals = 0x00;

        /* write rolling sequence while not connected */
        print_rolling_sequence();
        /* wrap output at 80 columns ... */
        if (output_width_count++ > 79) {
            output_width_count = 0;
            Serial.println("");
        }
        was_connected = false;
    } else {
        if (!was_connected) {
            was_connected = true;
            device = GamecubeController1.getStatus().device;
            Serial.print("READY ");
            print_hex16(device);
            Serial.println("!");
            output_width_count = 0;
        }
    }

    /*
     * We need to read even if disconnected to make sure
     * that wavebird controllers connect properly (they use
     * a two stage connection process, as the dongle is always
     * connected but the controller only connects when activated).
     */
    if (GamecubeController1.read()) {
        uint8_t msx_joystick_signals = 0x00;

        report = GamecubeController1.getReport();

        /* Directional buttons (D-Pad) */
        if (report.dup)
            msx_joystick_signals |= (1<<PORT_MSX_JOYSTICK_UP);
        if (report.ddown)
            msx_joystick_signals |= (1<<PORT_MSX_JOYSTICK_DOWN);
        if (report.dleft)
            msx_joystick_signals |= (1<<PORT_MSX_JOYSTICK_LEFT);
        if (report.dright)
            msx_joystick_signals |= (1<<PORT_MSX_JOYSTICK_RIGHT);

        /*
        * Digital Equivalent to directional buttons using the analog stick.
        * From center/origin: up and right is positive, down and left is negative.
        */

        /* before activating UP check that DOWN is not activated */
        if ((report.yAxis > axis_threshold_max) && !(msx_joystick_signals & (1<<PORT_MSX_JOYSTICK_DOWN)))
            msx_joystick_signals |= (1<<PORT_MSX_JOYSTICK_UP);

        /* before activating DOWN check that UP is not activated */
        if ((report.yAxis < axis_threshold_min) && !(msx_joystick_signals & (1<<PORT_MSX_JOYSTICK_UP)))
            msx_joystick_signals |= (1<<PORT_MSX_JOYSTICK_DOWN);

        /* before activating LEFT check that RIGHT is not activated */
        if ((report.xAxis < axis_threshold_min) && !(msx_joystick_signals & (1<<PORT_MSX_JOYSTICK_RIGHT)))
            msx_joystick_signals |= (1<<PORT_MSX_JOYSTICK_LEFT);

        /* before activating RIGHT check that LEFT is not activated */
        if ((report.xAxis > axis_threshold_max) && !(msx_joystick_signals & (1<<PORT_MSX_JOYSTICK_LEFT)))
            msx_joystick_signals |= (1<<PORT_MSX_JOYSTICK_RIGHT);

        /* trigger buttons */
        if (report.a)
            msx_joystick_signals |= (1<<PORT_MSX_JOYSTICK_TRIGGER1);
        if (report.b)
            msx_joystick_signals |= (1<<PORT_MSX_JOYSTICK_TRIGGER2);

        curr_msx_joystick_signals = msx_joystick_signals;
    }
    __update_msx_signals(curr_msx_joystick_signals);
}

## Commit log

2024-04-08 Initial commit.
    [msx-joydolphin-v2-case.dxf, msx-joydolphin-v2.kicad_pcb, msx-joydolphin-v2.kicad_sch]
2024-04-20 v2-build1c: prototype built
    [msx-joydolphin-v2.kicad_pcb, msx-joydolphin-v2.kicad_sch]
2024-04-27 acrylic enclosure updated
    [msx-joydolphin-v2-case-acrylic-3mm-ready-to-lasercut.dxf]

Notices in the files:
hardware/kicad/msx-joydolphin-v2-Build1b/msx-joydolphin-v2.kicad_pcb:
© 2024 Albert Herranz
